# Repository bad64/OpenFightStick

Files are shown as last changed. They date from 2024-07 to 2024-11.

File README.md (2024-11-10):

  

# Open-source 3D printable fightstick cases for the crafty warrior

Well... yeah that's about all there is to say. Peek the README files inside the folders for more info !

## Tools needed

- A 3D printer, preferably with a build surface at least 300 by 300 millimeters
	- Files for 220 x 220 build plates will be made available if possible
- A screwdriver adapted to whatever screws you pick (Phillips, Pozidriv, Hex... the choice is yours mate, you can even use Torx Security if you ~~feel like a soulless bastard~~ really just don't want anybody to get into your *open-source* controller, I'm not judging ~~I absolutely am judging~~)
- Some fine grit sandpaper, 500 and above (not needed per se but always nice to have in case a hole is too tight)
- A drill, Dremel, or pin vise with appropriate bits, usually 3 and 4mm (ditto)
- A soldering iron
- Lots of M3 heat set inserts
- 5.5mm by 2mm square nuts
- Flush cutters
- A lighter to burn up the angel hair (or y'know just *tune your printer*, that also works)

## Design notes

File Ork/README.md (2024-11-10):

# O.R.K.
## Regular fightstick case

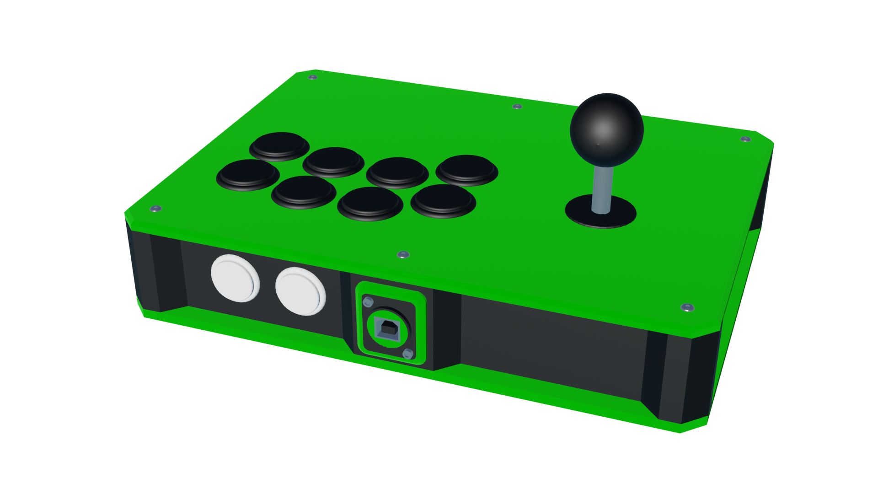
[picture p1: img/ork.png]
Waaaaagh !


---

This case is intended for a (relatively) compact build with all the features you'd normally expect in a modern fightstick.

## Acknowledgements

- [Buttercade](https://www.etsy.com/shop/BUTTERCADE) for the Surround and Support project
- [Junk Food Arcades](https://junkfoodarcades.com) for the Snack Box v2, which genuinely coincidentally happen to share a lot of general shapes with this project)

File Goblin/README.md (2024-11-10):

# G.O.B.L.I.N.
## Artwork-friendly Smashbox-style modular case

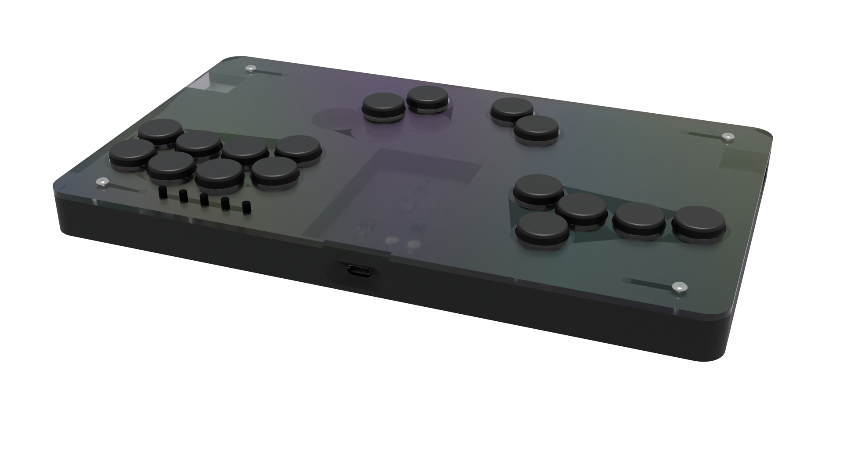
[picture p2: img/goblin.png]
I was rendered in Cycles and took like an hour... but at least I'm not EEVEE


---

This case is intended for a flat, Smashbox-style case and custom PCB with *either* Cherry MX style or Kailh Choc *v1* style switches.

> [!IMPORTANT]
> This build cannot, to the best of my knowledge and skill, be safely split to fit on a standard 220x220mm build plate.
> You **will** need at least a 300x300mm build plate.

## Materials needed

- 4 M3 x 6 countersunk screws to attach the bottom plate to the body
- 4 M3 x 6 button or machine head screws to attach the top plate to the body
- 8 M3 heat set inserts
- 5 through hole 15mm (or taller) 6x6 tactile switches
- A bunch of *either* MX style or Kailh Choc switches and corresponding hotswap sockets if you want them to be removable (big fan of Kailh Speed Navy switches here)
	- You *can* mix and match them and have both sockets soldered at the same time; why would you though ?
- A [board]()
- A [laser cut acrylic plate](Cut\ files), 3mm thick

## Printing

- Main body: Tested mainly in PLA, PETG/PCTG/ABS/nylon probably work too
	- Infill is a bit whatever, I use 20% gyroid, up to your taste and filament
	- Tree supports mandatory for the USB-C slot
- Bottom plate: about the same as above applies
- Caps:
	- MX style: See [Rana Labs' keycaps](https://github.com/rana-sylvatica/circle-keycaps)
	- Choc style: TBD

## Building

- Print the body
- Remove support material inside the USB-C hole
- (Optional) Touch up the holes using a pin vise or something similar so the inserts fall into place easier
- Add heat-set inserts to the body
- Assemble the PCB
- Place PCB inside the body
- (Optional) Add artwork
- Place acrylic panel and screw it in place
- Place caps onto switches (do this **BEFORE** putting them on the PCB)
- Seat switches inside their assigned slots (hold the hotswaps against the board while pushing the switches in)
- Place bottom panel and screw it in place
- Plug your board in and install the firmware

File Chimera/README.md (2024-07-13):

# C.H.I.M.E.R.A
## When you absolutely need every option

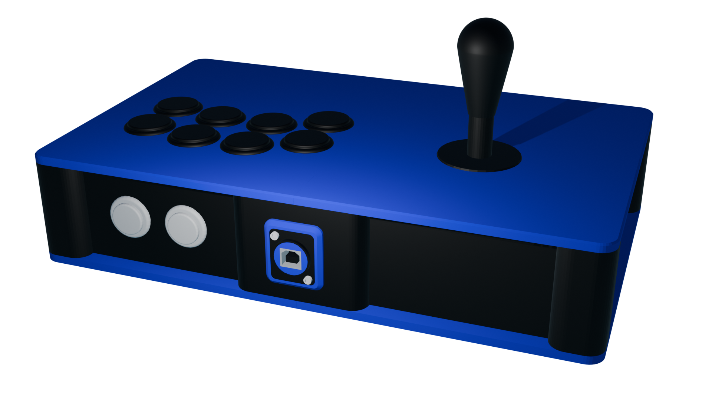
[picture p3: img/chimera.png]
Chonky boi


---

This case is intended for a complete build that sacrifices (a bit of) portability for versatility.
Unlike other models, all the STL files should fit on a standard 220x220mm build plate from the get go (it's a bit of a tight fit though but it should be okay so long as you don't need a brim or raft)

## Materials needed

In general:
- 8 5.5x2mm square nuts
- 8 M3x10 countersunk screws
- 24 10 x 3mm round magnets
- Filament for the body and plates
	- Not an endorsement, but I use PolyMaker's PolyTerra PLA line for my builds (matte rules !). You can make the contrast even more striking by having one filament matte and the other glossy
- A Brook board of your choosing (or GP2040 board if you can grab one where you live, even better)
- Cables and wires to connect the above to the rest of the hardware (usually a USB B to A and a wire harness)
	- **The 20pin Brook harness is mandatory if you mount the board to the underside of the top right panel.** If you don't you can use the 20 pin terminals just fine, otherwise you may need a riser
- One Neutrik USB A to B connector
- 2 M3x40 screws and matching nuts to mount the Neutrik connector (head to taste; I like machine head for that purpose)
- 5 24mm arcade buttons for START, SELECT and HOME, L3 and R3
- (OPTIONAL) Four extra nuts and button or machine head screws to mount the Brook board to the top plate (you don't *need* to but it's always a plus)
- Glue, or if you're extra paranoid, two part epoxy
- (OPTIONAL) 20mm rocker switches (one SPST for the tournament lock, one SPDT for the LS/DP/RS switch)

For the joystick based top left halves **except the American one**:
- 4 5.5x2mm square nuts
- 4 M3 screws, any length between 4 and 6mm should work (if not use spacers, don't screw through your top plate)

For the American chonky boi:
- 4 M5 square nuts
- 4 M5 screws (same deal as above)

For the buttons based top left halves:
- As many 24mm **screw-in** buttons as you wish to connect (within reason)

For the top right halves:
- 6 to 8 30mm **screw in** buttons of your choosing

## Printing

- Slice the body file
	- Add pauses to insert the nuts and magnets (you need to pause at the start of the layer that will cover and enclose the nut; I suggest watching tutorials on "how to add magnets to 3D prints" to get a feel on how to do this in your slicer)
	- Add support blockers to the nut and magnet holes and the Neutrik mounting points. Make sure the support blockers cover the entire holes !
- Print the body parts. This is the longest part to print so I recommend making sure you'll be around to add the nuts in order to minimize downtime. Unless you have a MMU or are *that* confident in your ability to remove supports, I suggest using PLA over any other material. If you do have a MMU, PETG works really well too. (Haven't tested any other filament)
- Do the same pause/filament change trick for the top panels to add nuts if needed. Slice the plates upside down
	- Don't add blockers to the Brook mounting holes if you don't intend to mount it
- Then print the plates !
- (OPTIONAL) Print the Neutrik surround and support in the same material/color as the plates
- (OPTIONAL) If your screws are too long to properly attach the mainboard, print a spacer !

## Assembly

> [!NOTE]
> This is how *I* would proceed. At some point if you've made it this far I would assume you know your own DEX stat better than I do and can opt for a different build order.

Assemble the frame; Apply your adhesive of choice, preferably using a thin modeling brush, to the tongues on the left and right side brackets. Insert them into the front and back joints. This is a very tight fit and depending on your printer's level of tuning, you might need to apply some force.

Open up the Neutrik connector and reverse it so that the USB-B connector faces outside. Mount the Neutrik connector to the frame. Use a wrench or pliers to tighten the nuts.

Screw the board to the top right panel. Screw the buttons into the right panel. Screw the option buttons to the right side of the frame, and check that they are not overlapping with the main buttons (they *shouldn't*, but even with my trove of hardware I cannot test every possible case).

Insert the magnets into your top plates. Use all-purpose pliers if you need to (add some cloth between the jaws and plate if you're afraid of damaging anything)

> [!TIP]
> Depending on its length you may want to add the USB cable now so that it sits out of the way from the regular wiring. It mostly depends on which side you tend to open your stick by and how often; I go through the bottom so having the USB cable under the rest of the harness helps me, but to each their own !

Connect the option buttons first by snaking them through the top panel buttons. It's a really tight fit, unfortunately, but it's pretty feasible IMO. Then wire up the ground chain for the main buttons, kicks, punches, and finally whichever directional method you choose.

Screw in the bottom panels. You might need to compress the wiring a little bit.

## Acknowledgements

- [Buttercade](https://www.etsy.com/shop/BUTTERCADE) for the Surround and Support project
- [Junk Food Arcades](https://junkfoodarcades.com) for the Snack Box v2, which genuinely coincidentally happen to share a lot of general shapes with my projects)

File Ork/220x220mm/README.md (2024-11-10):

> [!IMPORTANT]
> These files are made for a 220x220mm print surface. Obviously, nothing prevents you from printing them on a larger printer, but if you have anything above 300x300mm, I would definitely recommend using those files simply because they need a little less hardware.

## Materials needed

In general:
- 16 M3 heat-set inserts
- Half of that number M3x10 button-head screws (I recommend hex screws, Phillips sucks)
- And the other half M3x10 countersunk screws
- Filament for the body and plates
	- Not an endorsement, but I use PolyMaker's PolyTerra PLA line for my builds (matte rules !). You can make the contrast even more striking by having one filament matte and the other glossy
- A Brook board of your choosing (or GP2040 board if you can grab one where you live, even better)
- Cables and wires to connect the above to the rest of the hardware (usually a USB B to A and a wire harness)
	- **The 20pin Brook harness is mandatory if you opt to screw the board to the top panel.** If you don't, you can use the screw terminals just fine. If you run your own custom sleeved wires for maximum aesthetics you might want to get a riser but it should work otherwise
- One Neutrik USB A to B connector
- 2 M3x40 screws and matching nuts to mount the Neutrik connector (head to taste; I like machine head for their look)
- 3 24mm arcade buttons for START, SELECT, and HOME
- Glue, or if you're really paranoid, two part epoxy
- (OPTIONAL) Four 5.5x2mm square nuts and button or machine head screws to mount the Brook board to the top plate (you don't *need* to but it's always a plus)

For the Sega 2P builds:
- One lever with Japanese mounting points
	- All Sanwa, Seimitsu, and Qanba levers should fit (not a hundred percent sure about the Hori Hayabusa)
	- Crown levers with the -FJ suffix will fit
	- All (known) Fanta levers will fit
	- **American levers/Eurosticks will not fit**
- Four 5.5x2mm square nuts to mount the lever to
- Four button or machine head M3 screws (any length between 3 and 6mm *should* work. Use spacers if needed, just be careful to not screw through the panel)
- The appropriate top plate for your lever (Pick the 35mm hole if you have a full collar Korean lever, otherwise the 24mm one)
- 8 **screw-in** 30mm buttons

For the WASD leverless build:
- 12 24mm **screw-in** buttons

For the Hitbox leverless build:
- 11 24mm **screw-in** buttons
- 1 30mm **screw-in** button

## Printing

Print all the body files, depending on your exact build plate size you can definitely fit several parts at once to save time:
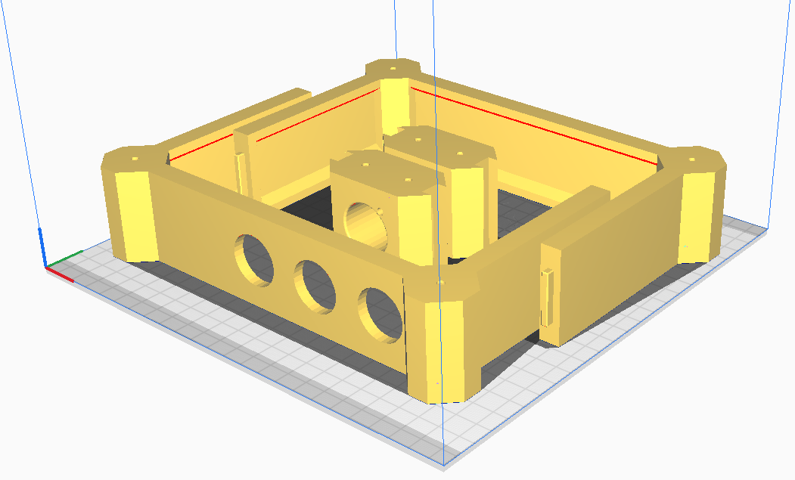
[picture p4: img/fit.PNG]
I was taught by a Tetris champion


Print the bottom plate twice, then whichever set of top plates you want. Add support blockers and filament changes/pauses (it doesn't really matter so long as the print head goes out of the way) on the lever mounting holes **at the start of the layer which will cover the nuts** if you plan on using one.

For the record, both Sega 2P top right plates are identical, but **that isn't true for the leverless builds**. Exercise caution !

If you do not wish to mount your board directly to the top right plate, print it as-is, otherwise again you will need to add a pause and support blockers.

**OPTIONAL:** Print the Surround and Support pieces for the Neutrik that you can find in the root Common folder.

## Assembly

> [!NOTE]
> This is how *I* would proceed. At some point if you've made it this far I would assume you know your own DEX stat better than I do and can opt for a different build order.

Assemble the frame; Apply your adhesive of choice, preferably using a thin modeling brush, to the tongues on the left and right side brackets. Insert them into the front and back joints. This is a very tight fit and depending on your printer's level of tuning, you might need to apply some force.

Heat up your soldering iron, and add the heat-set inserts. Let them cool down before attempting to screw anything in to let the plastic set.

Open up the Neutrik connector and reverse it so that the USB-B connector faces outside. Mount the Neutrik connector to the frame. Use a wrench or pliers to tighten the nuts.

Screw the board to the top right panel. Screw the buttons into the right panel. Screw the option buttons to the right side of the frame, and check that they are not overlapping with the main buttons (they *shouldn't*, but even with my trove of hardware I cannot test every possible case).

> [!TIP]
> Depending on its length you may want to add the USB cable now so that it sits out of the way from the regular wiring. It mostly depends on which side you tend to open your stick by and how often; I go through the bottom so having the USB cable under the rest of the harness helps me, but to each their own !

Connect the option buttons first by snaking them through the top panel buttons. It's a really tight fit, unfortunately, but it's pretty feasible IMO. Then wire up the ground chain for the main buttons, kicks, punches, and finally whichever directional method you choose.

Screw in the bottom panels. You might need to compress the wiring a little bit.

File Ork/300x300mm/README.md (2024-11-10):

> [!IMPORTANT]
> These files are made for a print surface that is *at least* 300x300mm.

## Materials needed

In general:
- 12 M3 heat-set inserts
- Half of that number M3x10 button-head screws (I recommend hex screws, Phillips sucks)
- And the other half M3x10 countersunk screws
- Filament for the body and plates
	- Not an endorsement, but I use PolyMaker's PolyTerra PLA line for my builds (matte rules !). You can make the contrast even more striking by having one filament matte and the other glossy
- A Brook board of your choosing (or GP2040 board if you can grab one where you live, even better)
- Cables and wires to connect the above to the rest of the hardware (usually a USB B to A and a wire harness)
	- **The 20pin Brook harness is mandatory if you opt to screw the board to the top panel.** If you don't, you can use the screw terminals just fine. If you run your own custom sleeved wires for maximum aesthetics you might want to get a riser but it should work otherwise
- One Neutrik USB A to B connector
- 2 M3x40 screws and matching nuts to mount the Neutrik connector (head to taste; I like machine head for their look)
- 3 24mm arcade buttons for START, SELECT, and HOME
- (OPTIONAL) Four 5.5x2mm square nuts and button or machine head screws to mount the Brook board to the top plate (you don't *need* to but it's always a plus)

For the Sega 2P builds:
- One lever with Japanese mounting points
	- All Sanwa, Seimitsu, and Qanba levers should fit (not a hundred percent sure about the Hori Hayabusa)
	- Crown levers with the -FJ suffix will fit
	- All (known) Fanta levers will fit
	- **American levers/Eurosticks will not fit**
- Four additional square nuts to mount the lever to
- Four button or machine head M3 screws (any length between 3 and 6mm *should* work. Use spacers if needed, just be careful to not screw through the panel)
- The appropriate top plate for your lever (Pick the 35mm hole if you have a full collar Korean lever, otherwise the 24mm one)
- 8 **screw-in** 30mm buttons

For the WASD leverless build:
- 12 24mm **screw-in** buttons

For the Hitbox leverless build:
- 11 24mm **screw-in** buttons
- 1 30mm **screw-in** button

## Printing

Print the body first as one piece. Orientation doesn't really matter so long as you use the right kind of supports for your filament.

Print the bottom plate, then whichever top plate you want. If you plan on using a lever or mounting your board to the top plate, add support blockers to the nut holes and filament changes/pauses (it doesn't matter as long as the print head moves out of the way) **at the start of the layer that will cover the nuts**.

**OPTIONAL:** Print the Surround and Support pieces for the Neutrik that you can find in the root Common folder.

## Assembly

> [!NOTE]
> This is how *I* would proceed. At some point if you've made it this far I would assume you know your own DEX stat better than I do and can opt for a different build order.

Use a soldering iron to add heat-set inserts to the holes. Let them cool down before attempting to screw anything in them so the plastic sets in.

Open up the Neutrik connector and reverse it so that the USB-B connector faces outside. Mount the Neutrik connector to the frame. Use a wrench or pliers to tighten the nuts.

Screw the board to the top panel if you want to do so. Screw the buttons into the panel, then mount the panel to the frame. Screw the option buttons to the right side of the frame, and check that they are not overlapping with the main buttons (they *shouldn't*, but even with my trove of hardware I cannot test every possible case).

> [!TIP]
> Depending on its length you may want to add the USB cable now so that it sits out of the way from the regular wiring. It mostly depends on which side you tend to open your stick by and how often; I go through the bottom so having the USB cable under the rest of the harness helps me, but to each their own !

Connect the option buttons first by snaking the wires through the top panel buttons. It's a really tight fit, unfortunately, but it's pretty feasible IMO. Then wire up the ground chain for the main buttons, kicks, punches, and finally whichever directional method you choose.

Screw in the bottom panel. You might need to compress the wiring a little bit.

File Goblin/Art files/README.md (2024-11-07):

I think you know the drill. Pick the file corresponding to your layout of choice.

Don't forget to commission a local artist and reward them for your hard work ! Or do it yourself if you're an artist, that also works. Just don't use AI. I can't enforce that but I can still try to get you to consider doing things the Right Way <sup>TM</sup>.

Print at 1:1 scale on A3 paper, preferably border to border since that's the canvas size. Print on poster paper, or failing that, the heaviest paper your print shop carries.

Use an exacto knife or a scalpel with a ruler to *carefully* cut out your art according to instructions. Install and make people wistfully gaze at your Goblin thinking "Damb, maybe I should get one myself".

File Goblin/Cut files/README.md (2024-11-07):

Those files are for getting your own acrylic plates cut. If you're looking for the artwork related files, they're in "Art files".

Full version uses all 20 buttons; Lite version reduces the count to 17.

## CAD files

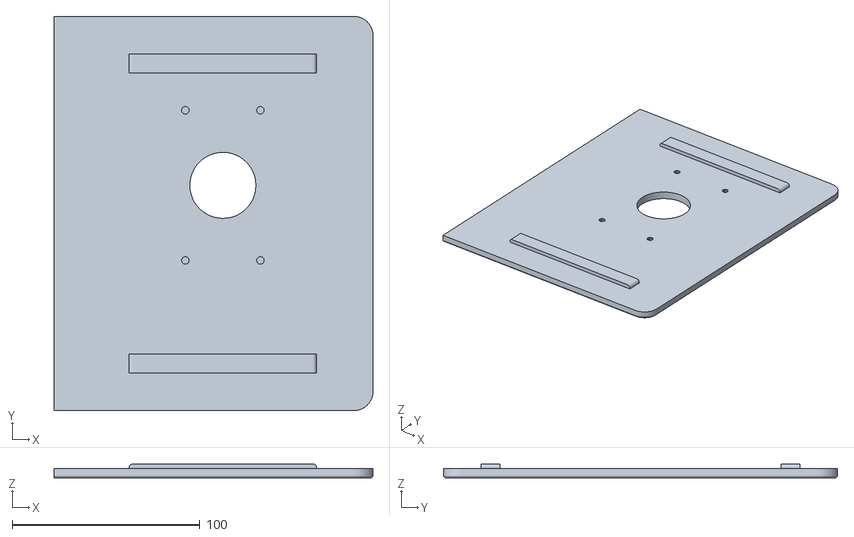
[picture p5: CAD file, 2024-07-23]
Chimera/STL/Top/Left/Chimera_TopLeft_FullCollar.stl
170.0 x 210.0 x 7.50

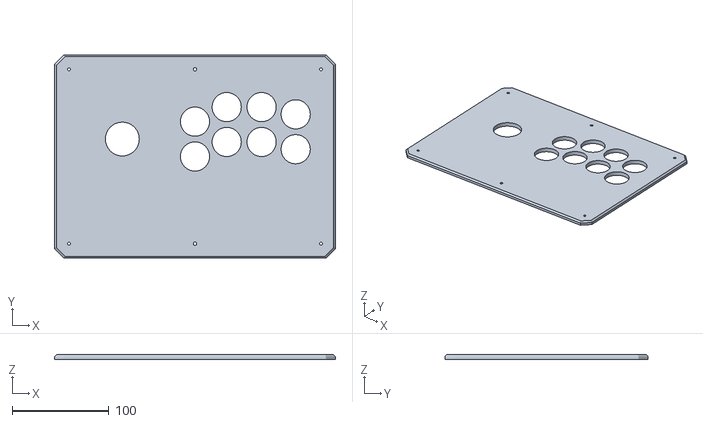
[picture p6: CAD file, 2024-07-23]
Ork/300x300mm/STL/Top/top_s2p_fullcollar.stl
290.0 x 210.0 x 5.00

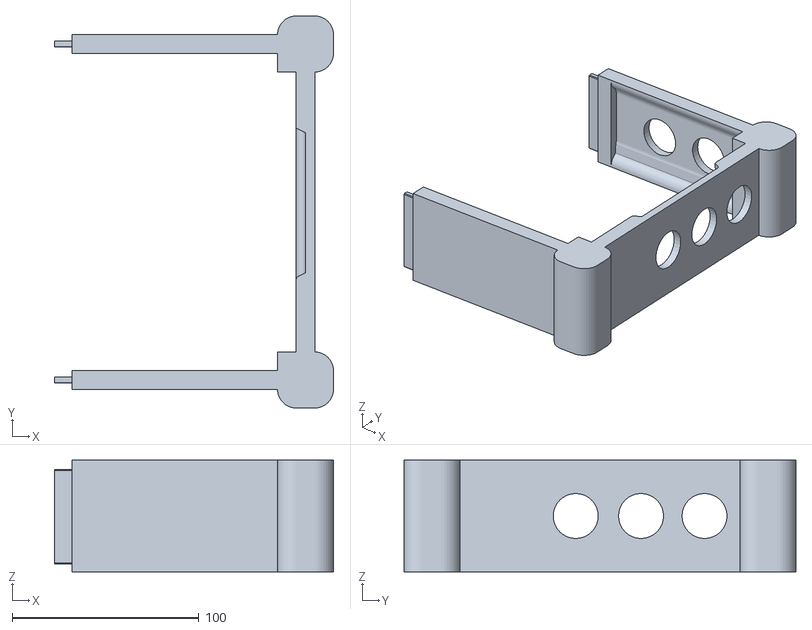
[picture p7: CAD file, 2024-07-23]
Chimera/STL/Chimera_Right.stl
149.5 x 210.0 x 60.0

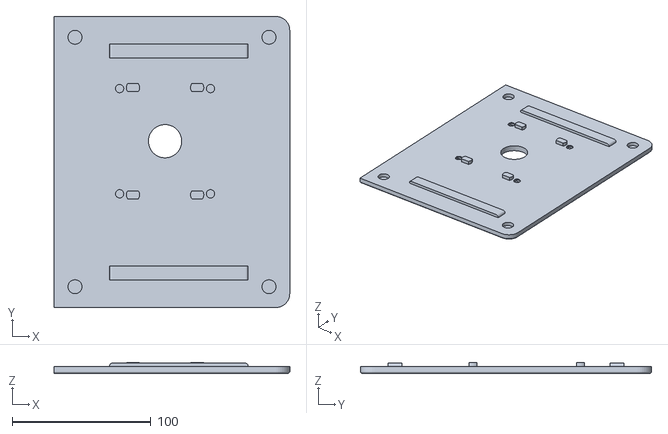
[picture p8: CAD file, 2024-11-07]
Chimera/STL/Top/Left/Chimera_TopLeft_American.stl
170.0 x 210.0 x 8.00

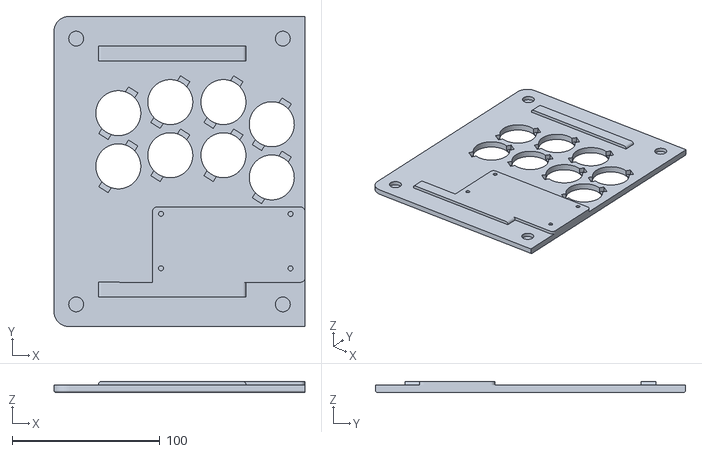
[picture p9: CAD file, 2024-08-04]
Chimera/STL/Top/Right/Chimera_Sega2P_30mm.stl
170.0 x 210.0 x 7.50

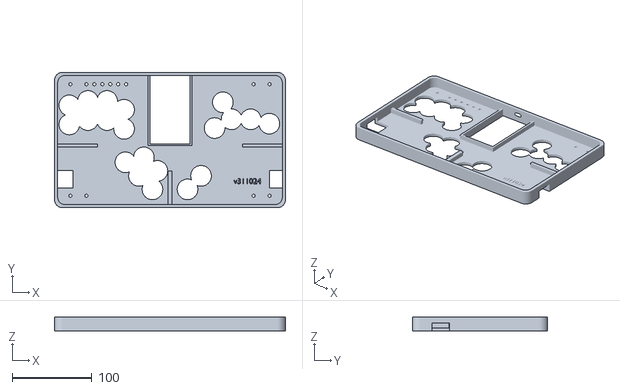
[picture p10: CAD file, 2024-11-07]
Goblin/Print files/Body.stl
290.0 x 170.0 x 18.1

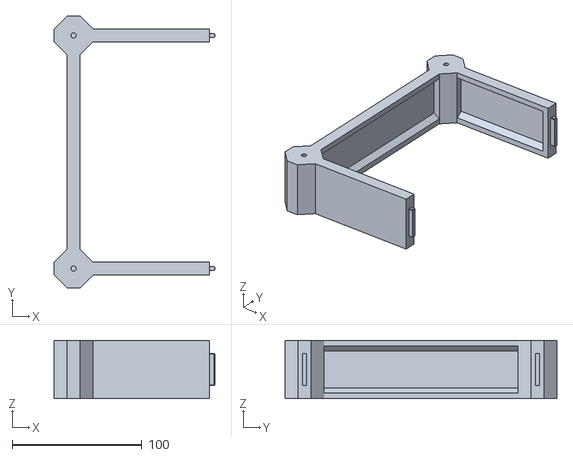
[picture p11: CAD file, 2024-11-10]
Ork/220x220mm/STL/Body Left.stl
124.0 x 210.0 x 45.0

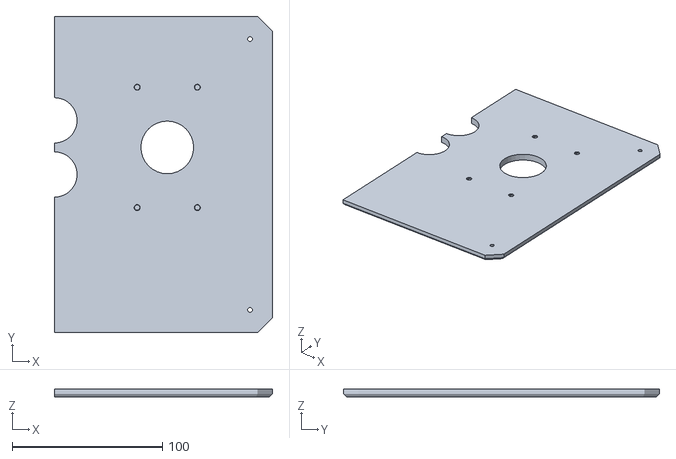
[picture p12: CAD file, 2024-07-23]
Ork/220x220mm/STL/Top Panel/Sega 2P with Full Collar/S2P FC top left.stl
145.0 x 210.0 x 5.00

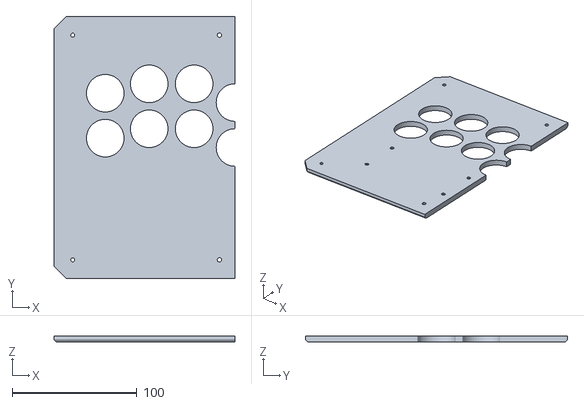
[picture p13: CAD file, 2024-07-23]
Ork/220x220mm/STL/Top Panel/Sega 2P/S2P top right.stl
145.0 x 210.0 x 5.00

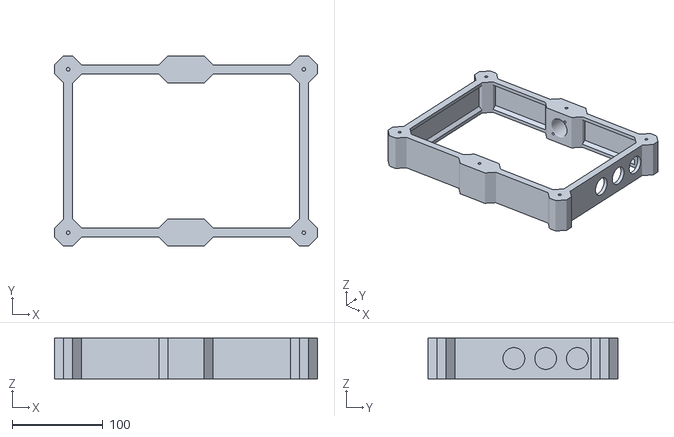
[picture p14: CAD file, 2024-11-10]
Ork/300x300mm/STL/body.stl
290.0 x 210.0 x 45.0

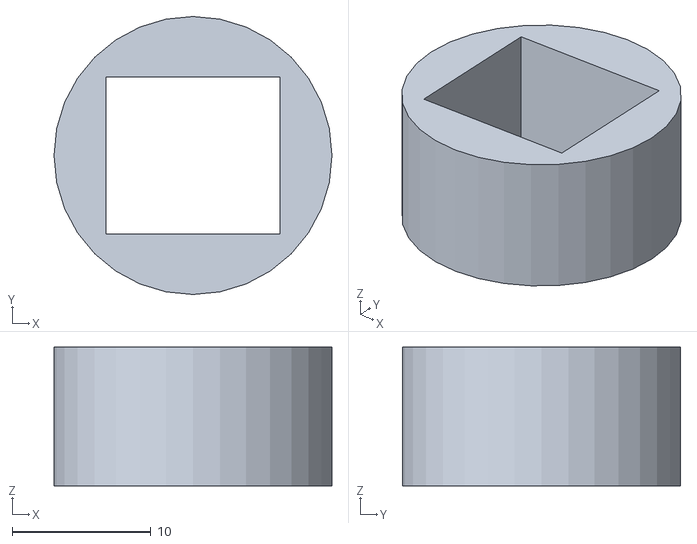
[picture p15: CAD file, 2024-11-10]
Ork/Common/Support.stl
20.0 x 20.0 x 10.0

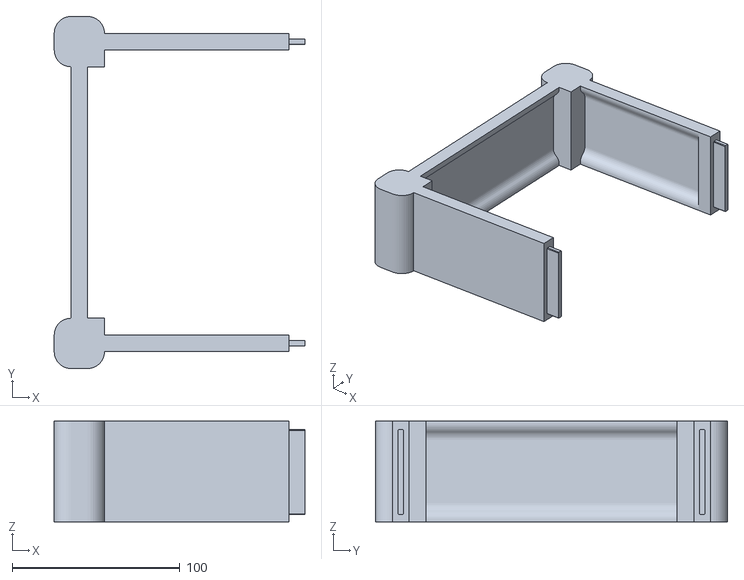
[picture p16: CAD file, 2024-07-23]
Chimera/STL/Chimera_Left.stl
149.5 x 210.0 x 60.0

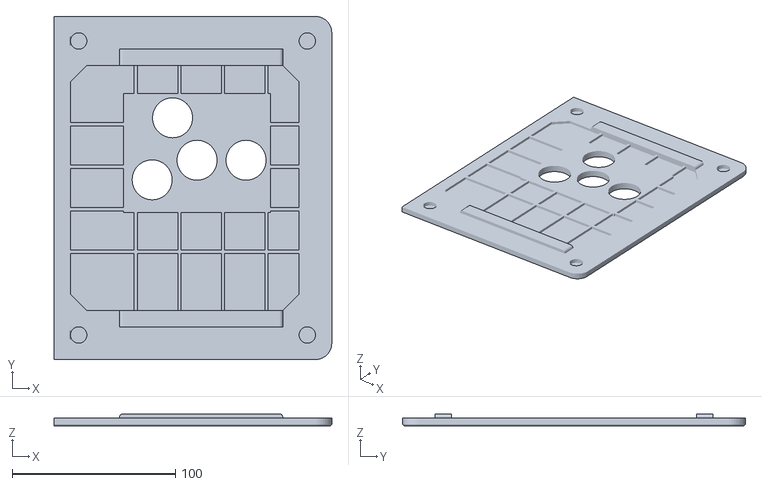
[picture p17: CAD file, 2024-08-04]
Chimera/STL/Top/Left/Chimera_WASD.stl
170.0 x 210.0 x 7.50

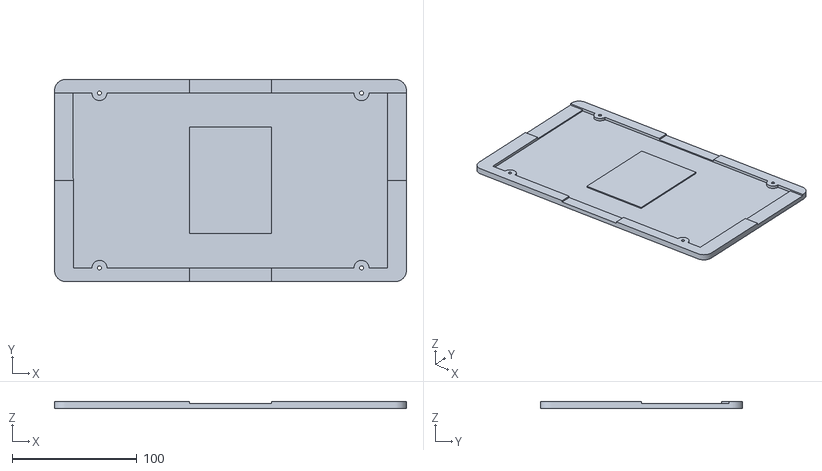
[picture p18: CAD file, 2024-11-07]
Goblin/Print files/Bottom plate.stl
282.0 x 162.0 x 5.70

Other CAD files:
Ork/220x220mm/STL/Top Panel/WASD/WASD top left.stl
Ork/300x300mm/STL/Top/top_wasd_plus.stl
Ork/220x220mm/STL/Body Front Joiner.stl
Chimera/STL/Chimera_Back.stl
Chimera/STL/Chimera_Bottom_Left.stl
Chimera/STL/Chimera_Bottom_Right.stl
Chimera/STL/Chimera_Front.stl
Chimera/STL/Top/Left/Chimera_TopLeft_NoCollar.stl
Chimera/chimera.blend
Goblin/goblin.blend
Ork/220x220mm/STL/Body Back Joiner.stl
Ork/220x220mm/STL/Body Right.stl
Ork/220x220mm/STL/Bottom.stl
Ork/220x220mm/STL/Top Panel/Sega 2P/S2P top left.stl
Ork/220x220mm/STL/Top Panel/WASD/WASD top right.stl
Ork/300x300mm/STL/Top/top_s2p.stl
Ork/300x300mm/STL/Top/top_wasd.stl
Ork/300x300mm/STL/bottom.stl
Ork/Common/Brook Spacer.stl
Ork/Common/Surround.stl

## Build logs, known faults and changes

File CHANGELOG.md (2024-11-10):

10112024:
- Gnome/Goblin: (actual changes dated from November 7th; forgot to update this file)
	- Merged the projects (under the Goblin name) as the distinction is pretty much unneeded in the end
	- Reworked the entire case to use Cherry MX style switches && heat-set inserts
- Ork:
	- Changed all body holes to use heat-set inserts instead of captive nuts (This change has the goal of removing the need for me to be near the printer so I can print while at work)
- README.md:
	- Updated hardware list for heat-set insert usage

04082024:
- Gnome:
	- Reworked almost the entire top layer geometry
	- Added 2 extra millimeters to the body to better align with the button caps
	- Swapped the board to the next generation (prototype)
	- Added Choc stand-ins and their caps
- Chimera:
	- Changed color to blue to match the filament I'm gonna use (purely aesthetic)
	- WASD plate has been made thicker again

23072024:
- General:
	- Widened holes on Ork and Chimera to accomodate Crown buttons
	- Published STL files
- Chimera:
	- S2P top right panel now has grooves for snap-in buttons
	- Front right only takes two option buttons instead of three to alleviate routing issues

13072024:
- General:
	- Redid the models for the Eurostick and JLF(/JLX/archetypal Japanese lever of the week)
	- Redid the renders for the Ork and Chimera
- Ork:
	- Now has a completely separate 220x220mm Blender file

03072024:
- General:
	- Added an "Acknowledgement" section to the README to give proper recognition to whomever I got inspiration from
- Chimera:
	- Body magnets are now double-stacked to improve adhesion
	- Plate magnets are now exposed (but since the body magnets aren't there is no actual magnet-on-magnet contact,, preventing damage)
	- WASD plate has been reworked to print slightly faster and use slightly less filament

19062024:
- General:
	- Redid all the visuals
- Gnome and Goblin:
	- Adjusted overall thickness to 21mm to allow the buttons to sink in fully into the panel, accounting for cap printing tolerances
- Chimera:
	- Fixed missing geometry on top plates
	- Added a plate for an American lever
	- Made a recess in the bottom left plate just to make sure there won't ever be any clearance issues with any lever
- Or[c|k]:
	- Renamed to Ork for no reason in particular

11062024:
- Started work on the Chimaera

09062024:
- Retired Dwarf as a mini case
- Reworked Orc from the ground up to be a midsize unibody

21032024:
- General:
	- Cleaned up Gnome and Goblin directories
	- Reworked manuals to be a little more exhaustive
	- Added refs to the OneBoard repo since it exists now
- Gnome:
	- Added a version of the body for captive M3 nuts
- Goblin:
	- Added divots on the bottom plate to allow space for non-flush screws

03032024:
- Changes to Gnome:
	- Now separate from the Goblin
	- Basically remade the entire model

02032024:
- Gnome has been merged into Goblin as its v4
	- Gnome will become something else in the near future
- Changes to Goblin:
	- Quite a lot of PCB modifications, body piece has been redesigned entirely
	- PCB files have been added
	- Pics of alternate layouts have been added

270224:
- Created CHANGELOG.md
- Created the G.N.O.M.E., a smaller, one-piece Goblin (might merge with Goblin in the long run)

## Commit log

2023-11-15 Images !
    [dwarf.blend, orc.blend]
2023-11-15 Build guides && STL files
    [backjoint.stl, bodyleft.stl, bodyright.stl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]
2024-01-21 Goblin v3
    [bodyleft.stl, bodyright.stl, bottom.stl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]
2024-02-13 Widened holes by 1.025x to account for tolerances
    [topleft.stl]
2024-03-02 Fused a Gnome and a Goblin
2024-03-02 Fused a Gnome and a Goblin (second attempt)
    [bodyleft.stl, bodyright.stl, bottom.stl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]
2024-03-02 Fused a Gnome and a Goblin (third attempt)
2024-03-18 i forgor
    [SSV06PLUS_body_embeddednuts.3mf, gnome_lite.dxf]
2024-03-21 Board's now public
    [SSV06PLUS_body_embeddednuts.3mf, gnome_lite.dxf]
2024-06-09 RewOrked the Or[c|k]
    [backjoint.stl, bodyleft.stl, bodyright.stl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]
2024-06-11 Added Chimaera
    [chimera.blend]
2024-06-19 Added Chimera
    [chimera.blend]
2024-06-19 Missing geometry
    [chimera.blend]
2024-07-13 Ork can now be printed on small printers
2024-07-23 STL files
    [BACK.stl, BOTTOM_LEFT.stl, BOTTOM_RIGHT.stl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]
2024-07-23 Added snap-in grooves to Chimera
    [LEFT.stl, S2P_30mm.stl]
2024-07-23 Added STL for right bracket
    [RIGHT.stl]
2024-08-04 Reworked the Gnome
    [BACK.stl, BOTTOM_LEFT.stl, BOTTOM_RIGHT.stl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]
2024-11-07 Complete rework of the Gnome/Goblin line
    [Body.stl, Bottom plate.stl, Chimera_TopLeft_American.stl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]
2024-11-10 Starting a general cleanup for easier production
    [Body Back Joiner.stl, Body Back.stl, Body Front Joiner.stl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]
2024-11-10 Removed nuts
    [Brook Spacer.stl, Support.stl, Surround.stl]

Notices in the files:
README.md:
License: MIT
